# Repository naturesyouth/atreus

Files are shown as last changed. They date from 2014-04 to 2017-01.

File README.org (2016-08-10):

* Atreus Keyboard

The Atreus is a mechanical keyboard designed primarily to match the
shape of human hands and to be as portable as possible. The case
measures 26x12cm and lacks even a number row, relying heavily upon the
=fn= key. There is a circuit board for this design, but it's also
possible to [[http://wiki.geekhack.org/index.php?title=Hard-Wiring_How-To][manually wire the matrix]].

I've seen a number of existing DIY 40% keyboard designs, but most of
them stagger the rows, which I find very annoying now that I've gotten
used to the columnar layout of the [[https://geekhack.org/index.php?topic=22780.0][Ergodox]]. In addition, many of the
designs I've seen waste a lot of room on the space bar, failing to
take into account the fact that the thumb is the strongest and most
versatile of the fingers. This design avoids both these problems while
taking a more couch-friendly single-piece approach.



See [[./changelog.md][the changelog]] for the various revisions made to the design since
its initial release.

** Kits

You can buy [[http://atreus.technomancy.us][Atreus kits]] that have all the parts you need along with
detailed assembly instructions from http://atreus.technomancy.us. If
you'd rather round up all the parts yourself, that's possible too
since the design is completely open source; see the bill of materials
below.

** Layout

Only a handful of punctuation marks (and no digits) are available
unshifted, and all the modifiers are on the bottom row:

 :    q     w     e     r     t       ||       y     u     i     o    p
 :    a     s     d     f     g       ||       h     j     k     l    ;
 :    z     x     c     v     b       ||       n     m     ,     .    /
 :   esc   tab  super shift bksp ctrl || alt space  fn     -     '  enter

The numbers and most of the punctuation are on the fn layer with a
numpad-style arrangement under the right hand:

 :    !    @     up     {    }        ||     pgup    7     8     9    *
 :    #  left   down  right  $        ||     pgdn    4     5     6    +
 :    [    ]      (     )    &        ||       `     1     2     3    \
 :   L2  insert super shift bksp ctrl || alt space   fn    .     0    =

The =L2= key switches it to the function layer, and tapping =L0= here
brings it back to the first layer.

 :  insert home    ↑    end  pgup     ||       ↑     F7    F8    F9   F10
 :    del   ←      ↓     →   pgdn     ||       ↓     F4    F5    F6   F11
 :                           reset    ||             F1    F2    F3   F12
 :              super shift bksp ctrl || alt space   L0             

The [[https://atreus.technomancy.us/tmk][firmware]] includes a number of other options, including
colemak, dvorak, and "software dvorak" which sends keycodes assuming
the OS will perform the translation into dvorak. Adding new layouts or
changing existing ones is easy.

** Parts

*** Switches

This layout has five modifiers and 37 non-modifiers.

I strongly prefer the feel and sound of tactile [[https://deskthority.net/wiki/Matias_switch#Click][Matias Clicky]]
switches for typing. However, I like having [[https://deskthority.net/wiki/Matias_switch#Linear][Matias Linear
switches]] switches on the modifier keys (ctrl, alt, super, shift, and
fn) because the tactile effect has no benefit for keys that are held
down, and giving a different response helps you learn the layout more
quickly.

For users that need to operate in sound-sensitive environments like
open offices or libraries,
[[http://deskthority.net/wiki/Matias_switch#Quiet_click][Matias Quiet
Click]] switches are a popular choice since they still offer tactility
without the noise. Other users prefer switches in the
[[http://deskthority.net/wiki/Cherry_MX][Cherry MX]] family, which use
different keycaps and switch plates but still work fine.

*** Diodes

In order to avoid ghosting, each switch needs a diode. The [[https://www.radioshack.com/product/index.jsp?productId=2062587][1N4148]] is a
readily-available choice, but nearly any signal diode would work.

*** Microcontroller

The circuit board design uses a [[http://www.pololu.com/product/3101][Pololu A-star micro]]. Hand-wired boards
can also use a [[http://www.pjrc.com/teensy/index.html][Teensy 2]] or [[http://arduino.cc/en/Main/ArduinoBoardMicro][Arduino Pro Micro]].

Be sure to get a microcontroller without headers so it will fit in
between the bottom layer and the plate. USB micro is preferred over
USB mini for this reason as well.

*** Keycaps

Caps for Matias switches are included in the official kits. Sculpted
caps are also available [[http://matias.ca/order/#keycaps][from Matias]] or by harvesting from old Alps
keyboards. It's recommended that you use unlabeled keys, because due
to the different sizes and orientations of certain keys (backspace,
shift, enter, etc) many of the labels will be incorrect if present.

Cherry switches have more options. This
[[http://keyshop.pimpmykeyboard.com/products/full-keysets/dsa-blank-sets-1][DSA-shaped base set]] (spherical indentations on the key, same profile for each
row) from Signature Plastics has 52 1x keys plus a few extras we won't
use. There are two "deep dish" keys in that set which you can place
under your index fingers on the home row to help guide your hands to
the right spot without looking. However, you only get a single 1.5x
keycap, and the middle two thumb keys both use them, so you might want
to pick up an extra.

** Circuit Board

The =atreus.rkt= program calculates switch and diode positions based
on row/column counts, spacing, and rotation factors, and emits a
=atreus.kicad_pcb= file. The board outline and traces are done by hand
and are stored in the =header.rktd= and =traces.rktd= files
respectively. The =atreus.kicad_pcb= file can be imported into [[http://kicad-pcb.org][Kicad]]
which can export Gerber files suitable for fabrication. A copy of the
Kicad PCB file is included in the repository if you don't want to
recompile it using Racket. Recompiling is only required if you want to
make changes to the procedurally-generated portions of the board.

Unfortunately most PCB fabricators require a minimum order of 10 or
so, making this impractical for one-offs. The PCB is not required, so
for one-off boards it's usually more sensible to stick with a [[http://atreus.technomancy.us/assembly-hand-wired.pdf][hand-wired build]] instead.

** Case

Layered laser-cut wood or acrylic. The [[http://geekhack.org/index.php?topic%3D54759.msg1304117#msg1304117][mark II case]] (EPS files in the
=case/= directory) features 8 screw holes and a kind of "stair step"
design around the top and bottom of the key clusters; mark I is
pictured below.

The =3mm-alps-all.eps= file contains the top plate, bottom plate, and
switch plate for Matias switches. =3mm.eps= contains the files for
Cherry boards. These pieces can all be cut on 3mm acrylic or wood. The
=spacer.eps= file should be cut on something thicker; between 4.5mm
and 6mm is recommended. The spacer needs to be at least as thick as
the connector of the USB cable you're using.

There is also a programmatically-implemented version of the case
written in OpenSCAD; it is more flexible (you can tweak the number of
rows/cols, etc and recompile) but it doesn't match the canonical case
exactly; in particular the screw holes are placed differently.

The original case (=case-mk-i.svg=) design is also included; it is
slightly less wide and has a minor asymmetry with the screws on the
bottom side.

On a 100W Epilog laser, the 3mm layers cut in about a minute and a
half. I did a run with 6mm acrylic of the other layers which took
nearly 6 minutes.

Wood cases should be finished with sandpaper and finishing oil/wax or
with [[https://atreus.technomancy.us/lacquer.pdf][lacquer]] which
takes longer but feels nicer.

** Firmware

The [[https://atreus.technomancy.us/tmk][TMK firmware]] is
recommended. You should be able to change into the =keyboard/atreus=
directory and run =make KEYMAP=qwerty= (or whichever variant you want)
to produce a qwerty =atreus.hex= file. You will probably want to
create your own layout once you've gotten a chance to try it and see
what works for you. See the readme for instructions of how to upload
it to the keyboard's controller.

There is also the older [[https://github.com/technomancy/atreus-firmware][atreus-firmware]] custom codebase which works
but has fewer features. It is recommended mostly for learning purposes
since the code is much simpler and easier to understand than TMK.

** Bill of Materials

If you don't want to get [[https://atreus.technomancy.us][the kit]] you can source parts yourself. (You
can also order a partial kit if you want to customize some of the
parts.) Using Cherry switches is cheapest unless you can find cheap
Alps-mount keycaps:

- 50 Matias or Cherry switches from mechanicalkeyboards.com
- 50 diodes from radio shack, ebay, or whatever
- 40 1x, 2 1.5x Keycaps from signatureplastics.com OR full keycap set from matias.com
- A-star micro from pololu.com
- Case materials from various sources
- Case laser cutting: 7.5 minutes on a 100W Epilog laser; varies by source
- USB micro cable, get anywhere

Recommended but optional:

- 5 linear Matias or Cherry switches

The base keycap set from Signature Plastics only has one 1.5x key,
which is used for the inner thumb keys. You can use a 1x key for one
of them, but it looks kind of tacky, so I recommend getting a second
1.5x keycap separately.

*** Other Tools

You'll need a soldering iron, solder, and a wire cutter. A multimeter
can come in handy for testing the connections but is optional. You'll
also need eight M3 machine screws with nuts; the length of the screws
depends on the thickness of the acrylic you use. You can add rubber
feet to the bottom to prevent the board from sliding around when
placed on a desk. You'll also need sandpaper and lacquer for the
wooden case.

If you are building a hand-wired board you will also need a glue gun,
hookup wire, and wire strippers.

** Assembly

See the [[https://atreus.technomancy.us/assembly.pdf][assembly instructions]] PDF.

Hand-wired boards will want the [[https://atreus.technomancy.us/assembly-hand-wired.pdf][previous edition of the assembly instructions]].

The LaTeX source to the assembly instructions is in the =assembly= directory.

** Inspiration

These fine projects all provided inspiration for various aspects of
the Atreus, as well as the folks on the =#geekhack= freenode channel.

- [[https://geekhack.org/index.php?topic=22780.0][Ergodox]]
- [[http://deskthority.net/workshop-f7/onehand-20-keyboard-t6617.html][OneHand]]
- [[http://blog.fsck.com/2013/12/better-and-better-keyboards.html][keyboard.io]]
- [[http://geekhack.org/index.php?topic=48718][ErgoT]]

** Builds

If you've built an Atreus, please add your name to [[https://github.com/technomancy/atreus/wiki/BuildLogs][the build logs wiki]].

There's also a [[https://atreus.technomancy.us/list][mailing list]] for people who have built or ordered an
Atreus or are interested in doing so.

** Orestes

A new [[https://www.flickr.com/photos/technomancy/14654421878][experimental build]] uses the [[http://pjrc.com/store/teensy31.html][Teensy 3]] microcontroller and
ARM [[https://github.com/technomancy/orestes/tree/teensy3][Forth-based]] firmware, but this is not yet suitable for general-purpose use.

** License

Copyright © 2014-2016 Phil Hagelberg and contributors

Released under the [[https://www.gnu.org/licenses/gpl.html][GNU GPL version 3]]

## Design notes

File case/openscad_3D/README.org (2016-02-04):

* OpenSCAD Atreus case design

This directory contains a copy =atreus_3D.scad= of the original OpenSCAD script =atreus_case.scad= that
generates Atreus case designs using a number of parameters and is rendered for 3D printing.

The main parameters are:

- =angle= : one half of the angle between the left and the right
  groups of keys
- =n_rows=, =n_cols= : number of rows and columns to use
- =staggering_offsets= : column staggering offsets
- =cable_hole_width= : width of the hole for the USB cable
- =hand_separation= : distance between the left and the right groups
  of keys
- =screw_hole_radius= : radius of screw holes
- =use_notched_holes= (boolean) : whether notched Cherry MX switch
  holes are desired

See comments in =atreus_case.scad= for details.

To use, open this script in OpenSCAD, select *Compile and Render
(CGAL)* in the *Design* menu, then select *Export as DXF...*.

Use OpenSCAD to export .stl as necessary.

Please note that the OpenSCAD version of the case is not a direct port
of the canonical DXF; the screw placement is a little bit different,
and the curve of the bottom edge sticks out a bit more.

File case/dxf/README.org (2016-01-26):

* Case design files

This directory contains design files for a laser cut Atreus case.

- =case_quartered.dxf= has spacers split into 4 parts to make it
  easier to fit everything into a 24 by 12 inch sheet.
- =case.dxf= contains the same design but uses a spacer made out one piece.
- =ready-for-ponoko.svg= is the file successfully used to make an
  Atreus case using Ponoko.
- =keys.dxf= contains Cherry MX switch holes with 1x1 and 1x1.5 key
  outlines. They can be used as building blocks for new case designs.

These files are missing the logo.

Unless you're getting this cut somewhere with size restrictions, you
should probably use the =.eps= files in the parent directory. These
also only work with Cherry MX switches, not Matias or Alps.

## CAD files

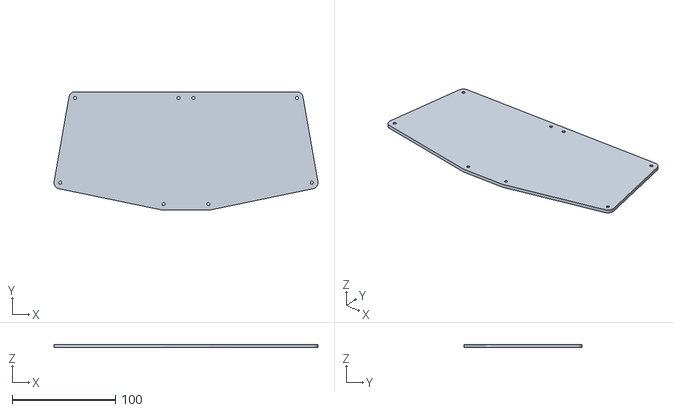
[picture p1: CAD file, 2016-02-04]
case/atreus_bottom.stl
255.3 x 114.5 x 3.00

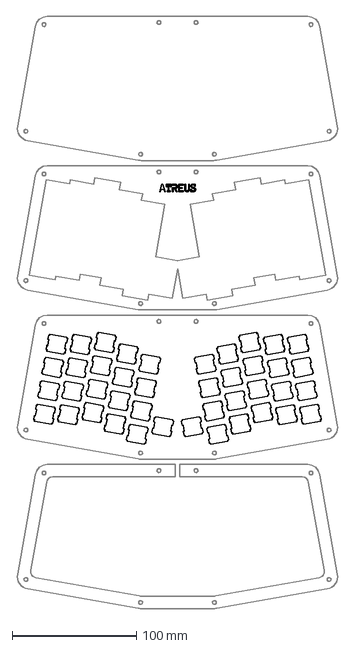
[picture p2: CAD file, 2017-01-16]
case/dxf/#case.dxf
258.8 x 475.8 mm

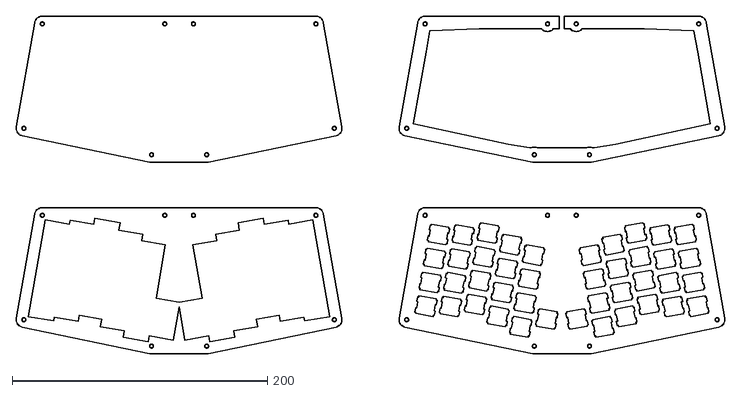
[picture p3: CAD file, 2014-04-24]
case/openscad/atreus_case.dxf
555.3 x 264.5

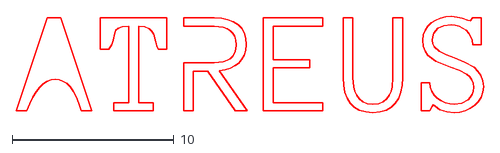
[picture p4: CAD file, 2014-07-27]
logo.dxf
28.9 x 5.95

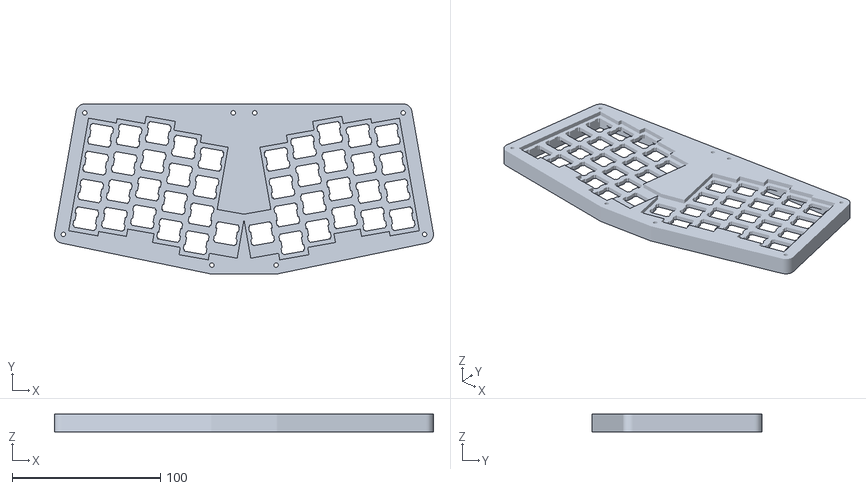
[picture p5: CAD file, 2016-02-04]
case/atreus.stl
255.3 x 114.5 x 12.0

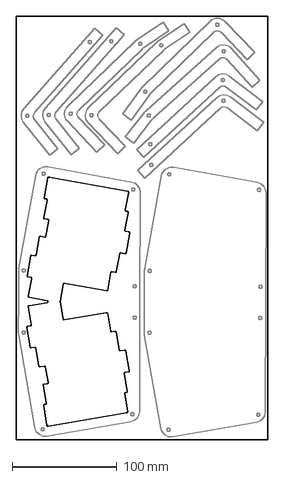
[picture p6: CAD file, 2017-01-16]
case/dxf/case-quartered-collapsed-double-hieght.dxf
239.6 x 404.2 mm

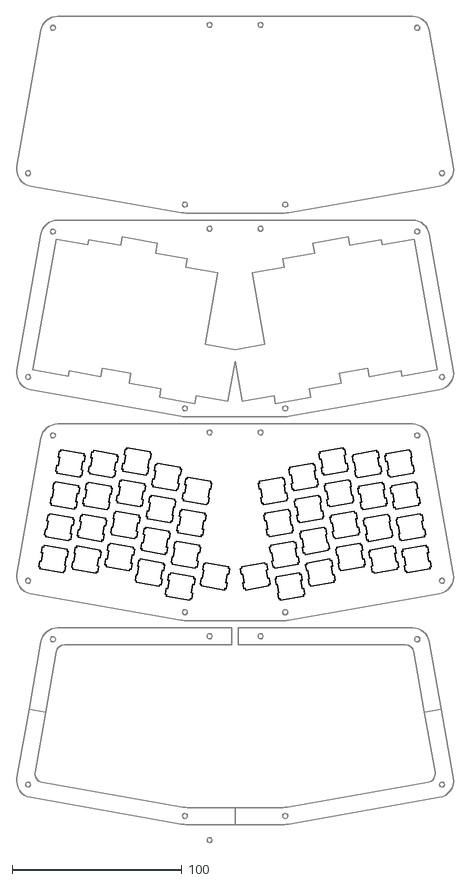
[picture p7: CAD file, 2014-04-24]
case/dxf/case-quartered.dxf
258.3 x 486.5

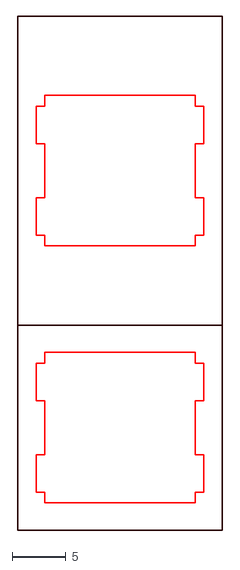
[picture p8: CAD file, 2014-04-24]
case/dxf/keys.dxf
19.1 x 47.8

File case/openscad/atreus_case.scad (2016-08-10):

// -*- mode: c -*-
/* All distances are in mm. */

/* set output quality */
$fn = 50;

/* Distance between key centers. */
column_spacing   = 19;
row_spacing      = column_spacing;

/* This number should exceed row_spacing and column_spacing. The
 default gives a 1mm = (20mm - 19mm) gap between keycaps and cuts in
 the top plate.*/
key_hole_size = 20;

/* rotation angle; the angle between the halves is twice this
   number */
angle = 10;

/* The radius of screw holes. Holes will be slightly bigger due
   to the cut width. */
screw_hole_radius = 1.5;
/* Each screw hole is a hole in a "washer". How big these "washers"
   should be depends on the material used: this parameter and the
   `switch_hole_size` determine the spacer wall thickness. */
washer_radius     = 4 * screw_hole_radius;

/* This constant allows tweaking the location of the screw holes near
   the USB cable. Only useful with small `angle` values. Try the value
   of 10 with angle=0. */
back_screw_hole_offset = 0;

/* Distance between halves. */
hand_separation        = 0;

/* The approximate size of switch holes. Used to determine how
   thick walls can be, i.e. how much room around each switch hole to
   leave. See spacer(). */
switch_hole_size = 14;

/* Sets whether the case should use notched holes. As far as I can
   tell these notches are not all that useful... */
use_notched_holes = true;

/* Number of rows and columns in the matrix. You need to update
   staggering_offsets if you change n_cols. */
n_rows = 4;
n_cols = 5;

/* Number of thumb keys (per hand), try 1 or 2. */
n_thumb_keys = 1;

/* The width of the USB cable hole in the spacer. */
cable_hole_width = 12;

/* Vertical column staggering offsets. The first element should
   be zero. */
staggering_offsets = [0, 5, 11, 6, 3];

/* Whether or not to split the spacer into quarters. */
quarter_spacer = false;

/* Where the top/bottom split of a quartered spacer will be. */
spacer_quartering_offset = 60;

module rz(angle, center=undef) {
  /* Rotate children `angle` degrees around `center`. */
  translate(center) {
    rotate(angle) {
      translate(-center) {
        for (i=[0:$children-1])
          child(i);
      }
    }
  }
}

/* Compute coordinates of a point obtained by rotating p angle degrees
   around center. Used to compute locations of screw holes near the
   USB cable hole. */
function rz_fun(p, angle, center) = [cos(angle) * (p[0] - center[0]) - sin(angle) * (p[1] - center[1]) + center[0],
                                     sin(angle) * (p[0] - center[0]) + cos(angle) * (p[1] - center[1])+ center[1]];

module switch_hole(position, notches=use_notched_holes) {
  /* Cherry MX switch hole with the center at `position`. Sizes come
     from the ErgoDox design. */
  hole_size    = 13.97;
  notch_width  = 3.5001;
  notch_offset = 4.2545;
  notch_depth  = 0.8128;
  translate(position) {
    union() {
      square([hole_size, hole_size], center=true);
      if (notches == true) {
        translate([0, notch_offset]) {
          square([hole_size+2*notch_depth, notch_width], center=true);
        }
        translate([0, -notch_offset]) {
          square([hole_size+2*notch_depth, notch_width], center=true);
        }
      }
    }
  }
};

module regular_key(position, size) {
  /* Create a hole for a regular key. */
  translate(position) {
    square([size, size], center=true);
  }
}

module thumb_key(position, size) {
  /* Create a hole for a 1x1.5 unit thumb key. */
  translate(position) {
    scale([1, 1.5]) {
      translate(-position) {
        regular_key(position, size);
      }
    }
  }
}

module column (bottom_position, switch_holes, key_size=key_hole_size) {
  /* Create a column of keys. */
  translate(bottom_position) {
    for (i = [0:(n_rows-1)]) {
      if (switch_holes == true) {
        switch_hole([0, i*column_spacing]);
      } else {
        regular_key([0, i*column_spacing], key_size);
      }
    }
  }
}

module rotate_half() {
  /* Rotate the right half of the keys around the top left corner of
     the thumb key. Assumes that the thumb key is a 1x1.5 key and that
     it is shifted 0.5*column_spacing up relative to the nearest column. */
  rotation_y_offset = 1.75 * column_spacing;
  for (i=[0:$children-1]) {
    rz(angle, [hand_separation, rotation_y_offset]) {
      child(i);
    }
  }
}

module add_hand_separation() {
  /* Shift everything right to get desired hand separation. */
  for (i=[0:$children-1]) {
    translate([0.5*hand_separation, /* we get back the full separation
                                       because of mirroring */
               0]) child(i);
  }
}

module right_half (switch_holes=true, key_size=key_hole_size) {
  /* Create switch holes or key holes for the right half of the
     keyboard. Different key_sizes are used in top_plate() and
     spacer(). */
  x_offset = 0.5 * row_spacing;
  y_offset = 0.5 * column_spacing;
  thumb_key_offset = y_offset + 0.5 * column_spacing;
  rotate_half() {
    add_hand_separation() {
      for (j=[0:(n_thumb_keys-1)]) {
        if (switch_holes == true) {
          switch_hole([x_offset + j*row_spacing, thumb_key_offset]);
        } else {
          thumb_key([x_offset + j*row_spacing, thumb_key_offset], key_size);
        }
      }
      for (j=[0:(n_cols-1)]) {
        column([x_offset + (j+n_thumb_keys)*row_spacing, y_offset + staggering_offsets[j]], switch_holes, key_size);
      }
    }
  }
}

module screw_hole(radius, offset_radius, position, direction) {
  /* Create a screw hole of radius `radius` at a location
     `offset_radius` from `position`, (diagonally), in the direction
     `direction`. Oh, what a mess this is. */
  /* direction is the 2-element vector specifying to which side of
     position to move to, [-1, -1] for bottom left, etc. */

  /* radius_offset is the offset in the x (or y) direction so that
     we're offset_radius from position */
  radius_offset = offset_radius / sqrt(2);
  /* key_hole_offset if the difference between key spacing and key
     hole edge */
  key_hole_offset = 0.5*(row_spacing - key_hole_size);
  x = position[0] + (radius_offset - key_hole_offset) * direction[0];
  y = position[1] + (radius_offset - key_hole_offset) * direction[1];
  translate([x,y]) {
    circle(radius);
  }
}

module right_screw_holes(hole_radius) {
  /* coordinates of the back right screw hole before rotation... */
  back_right = [(n_cols+n_thumb_keys)*row_spacing,
               staggering_offsets[n_cols-1] + n_rows * column_spacing];
  /* and after */
  tmp = rz_fun(back_right, angle, [0, 2.25*column_spacing]);

  nudge = 0.75;

  rotate_half() {
    add_hand_separation() {
      screw_hole(hole_radius, washer_radius,
                 [row_spacing, 0],
                 [-nudge, -nudge]);
      screw_hole(hole_radius, washer_radius,
                 [(n_cols+n_thumb_keys)*row_spacing, staggering_offsets[n_cols-1]],
                 [nudge, -nudge]);
      screw_hole(hole_radius, washer_radius,
                 back_right,
                 [nudge, nudge]);
    }
  }

  /* add the screw hole near the cable hole */
  translate([washer_radius - tmp[0] - 0.5*hand_separation,
             back_screw_hole_offset]) {
    rotate_half() {
      add_hand_separation() {
        screw_hole(hole_radius,
                   washer_radius,
                   back_right,
                   [nudge, nudge]);
      }
    }
  }
}

module screw_holes(hole_radius) {
  /* Create all the screw holes. */
  right_screw_holes(hole_radius);
  mirror ([1,0,0]) { right_screw_holes(hole_radius); }
}

module left_half(switch_holes=true, key_size=key_hole_size) {
  mirror ([1,0,0]) { right_half(switch_holes, key_size); }
}

module bottom_plate() {
  /* bottom layer of the case */
  difference() {
    hull() { screw_holes(washer_radius); }
    screw_holes(screw_hole_radius);
  }
}

module top_plate() {
  /* top layer of the case */
  difference() {
    bottom_plate();
    right_half(false);
    left_half(false);
  }
}

module switch_plate() {
  /* the switch plate */
  difference() {
    bottom_plate();
    right_half();
    left_half();
  }
}

module spacer() {
  /* Create a spacer. */
  difference() {
    union() {
      difference() {
        bottom_plate();
        hull() {
          right_half(switch_holes=false, key_size=switch_hole_size + 3);
          left_half(switch_holes=false, key_size=switch_hole_size + 3);
        }
    /* add the USB cable hole: */
    translate([-0.5*cable_hole_width, 2*column_spacing]) {
      square([cable_hole_width, (2*n_rows) * column_spacing]);
    }
      }
      screw_holes(washer_radius);
    }
    screw_holes(screw_hole_radius);
  }
}

module spacer_quadrant(spacer_quadrant_number) {
  /* Cut a quarter of a spacer. */
  translate([0, spacer_quartering_offset]) {
    intersection() {
      translate([0, -spacer_quartering_offset]) { spacer(); }
      rotate([0, 0, spacer_quadrant_number * 90]) { square([1000, 1000]); }
    }
  }
}
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

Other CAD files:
case/dxf/switchplate-250w.dxf
case/openscad_3D/atreus_3D.scad
case/dxf/case.dxf

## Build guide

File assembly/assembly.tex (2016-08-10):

\documentclass{article}
\title{Atreus Keyboard Assembly}
\date{ }
\usepackage{graphicx}
\usepackage{geometry}
\usepackage{wrapfig}
\newgeometry{margin=3cm}
\begin{document}
\setlength{\parindent}{0cm}
\maketitle
\section{Prerequisites}

In order to assemble your keyboard, you'll need your kit plus a few
other tools. The kit should contain these parts and a few spares:

\begin{itemize}
\item Case (top plate, switch plate, spacer, bottom plate)
\item Sandpaper
\item Finishing wax (mixture of beeswax and mineral oil)
\item Diodes (42)
\item Key switches (37 tactile or clicky, 5 red)
\item A-Star Micro controller
\item Printed circuit board (PCB)
\item Machine screws and nuts (8 each, 16mm M3 size)
\item Key caps (40 normal, 2 long)
\item USB micro cable
\item Rubber feet
\end{itemize}

You'll also need to have these on hand:

\begin{itemize}
\item Brush for applying finishing wax (a toothbrush will do)
\item Soldering iron and solder (thin solder and an iron with a sharp tip)
\item Wire cutters
\item Rags or paper towels to lay the parts down on during construction
\end{itemize}

\vspace{1em}

The latest version of this document can always be found
online.\footnote{http://atreus.technomancy.us/assembly.pdf} If you're
reading a black-and-white printed copy, you may find some of the
photos clearer in color onscreen. This copy describes the
circuit-board-based kit. If you are hand-wiring a board, see the older
assembly
guide.\footnote{http://atreus.technomancy.us/assembly-hand-wired.pdf}
The photos in this guide depict Matias switches, (with rectangular
switch stems) but you can use Cherry MX switches (with stems shaped
like a +) as well. The assembly steps are the same in either case.

\section{Sanding}

Start by sanding down both sides of each piece. You may want to
hold two pieces together while sanding for strength or placing it on a
flat surface you don't mind scruffing up; too much pressure on a
single plate could damage it.

\vspace{1em}
\noindent\makebox[\textwidth]{%
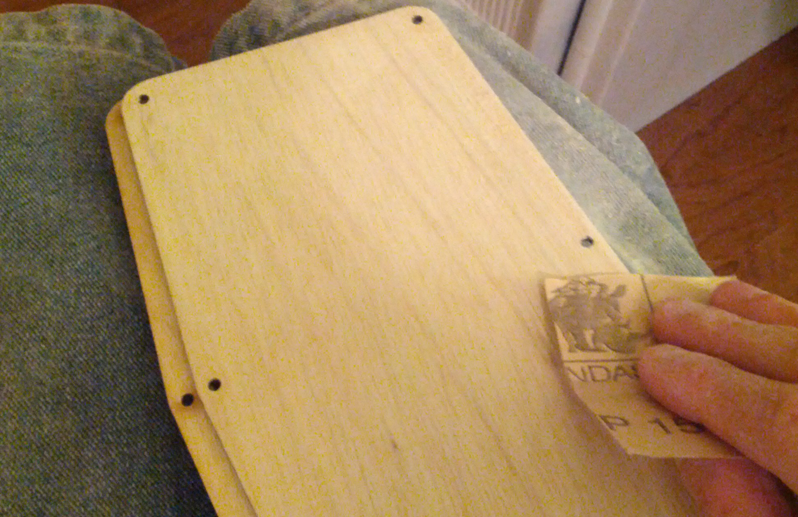
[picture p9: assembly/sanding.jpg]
}
\vspace{1em}

Keep in mind that the top side of the top plate and the bottom side of
the bottom plate are the only surfaces that are exposed to the touch
once the keyboard is fully assembled, so these will need the most
attention when sanding. You can sand the other surfaces as well just
to get the scorch marks off, but you don't need to worry about how
smooth the inner surfaces feel to the touch. Be sure to get all the
wood dust off the pieces before you go on. A clean tack cloth or other
fine cloth works well.

\section{Finishing}

You have two options when it comes to finishing. The easiest way is to
proceed with the wax/oil mixture included in the kit, but you can also
finish it with a spray lacquer. This requires buying more supplies and
takes longer, but it results in a sturdier, shinier
finish.\footnote{http://atreus.technomancy.us/lacquer.gif} The steps
for the lacquered finish are described in a separate
document,\footnote{http://atreus.technomancy.us/lacquer.pdf} and the
rest of this section describes the quicker finishing method.

\vspace{1em}

Some people don't like the look of the exposed edges charred from the
laser cutter. You can choose to sand off the charring, or alternately
cover it all with black ink from a sharpie for a more consistent look.

\vspace{1em}

Open up the wax/oil mixture. Apply some to the brush and start
spreading it over one side of each case piece. The color of the wood
will darken as it absorbs the oil. Try to ensure it's spread
evenly. Be more generous with the oil on the outer exposed
surfaces. Once you've spread it with the brush, you can use your
fingers to work the wax into the wood more deeply. If you need to
reapply the finishing in the future, butcher block conditioner is
readily available in stores and will do the job nicely.

\vspace{1em}
\noindent\makebox[\textwidth]{%
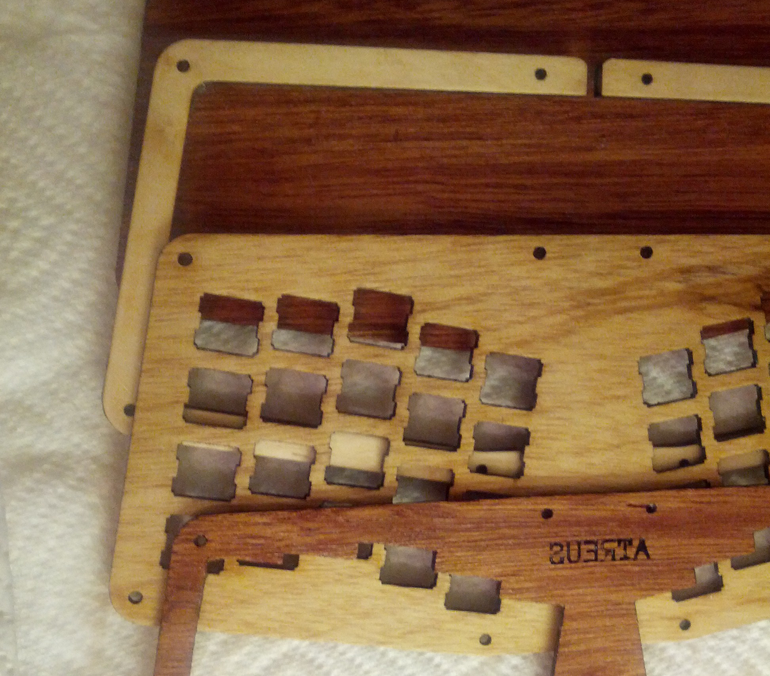
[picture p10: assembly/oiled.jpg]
}
\vspace{1em}

As your brush goes over the edges of the laser-cut wood, it will get
dirty from charred wood particles. After you've finished oiling one
side of each piece, it's best to wash out the brush. Be sure it's
fully dry before going on.

\section{Drying}

Once one side of each piece is finished, you'll need to lay them out
for a half hour or so to let them dry. Once one side is dry, repeat
the process on the other side. After you've finished the construction
you can come back and add another few coats to the outermost surfaces
for a smoother texture. Once it's dried for a while, wipe the excess
off. While you're waiting, you can start soldering the diodes and
controller onto the circuit board, but don't solder any switches in
before the switch plate is ready or you'll just need to remove them
later.

\section{Diodes}

If you've never soldered before, there are plenty of good
introductions online.\footnote{This one from Adafruit is great:
  https://learn.adafruit.com/adafruit-guide-excellent-soldering/tools}
Coat the tip of the hot iron thinly with some solder before you
start. The key is to use the iron to heat both parts of the joint for
a second or two, then bring in a dab of the solder and let it melt and
stick to the component and the circuit board pad.

\vspace{1em}

Take five diodes at a time and bend them into a U shape. Place them
into the diode holes next to each switch slot on the unlabeled side of
the board. Each diode has a black band on it; the band should be
pointing in the direction of the arrow on the printed side of the
board. Once all five are in, pinch the legs of the diodes together to
keep them from falling out, then flip the board over and solder them
in place. Make sure they don't protrude off the board more than necessary.

\vspace{1em}
\noindent\makebox[\textwidth]{%
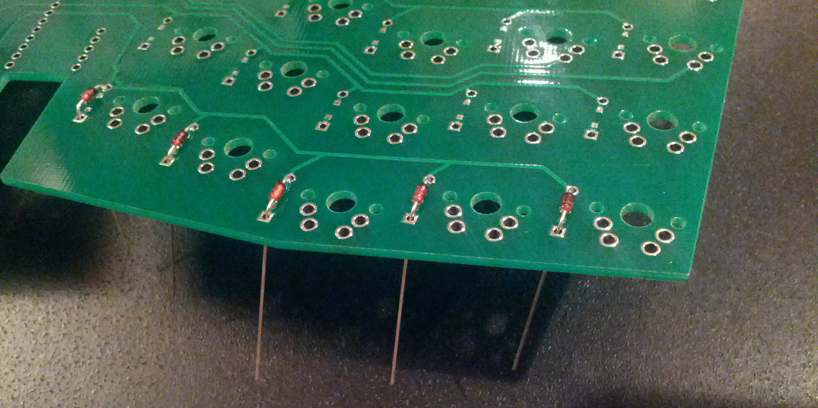
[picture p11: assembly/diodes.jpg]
  }
\vspace{1em}

In the photo the diodes are inserted from the back of the circuit
board, but it will work just as well to insert them from the front as
long as the black band is oriented correctly. Once they're soldered,
trim the diode legs with wire cutters. Grip the diode leg as you
trim it to keep it from flying across the room. Keep the diode legs;
they will be needed in the next step. Repeat until each diode position
is filled.

\section{Controller}

Once the diodes are in place, you can begin attaching the controller.
If the controller came in a pink bag with its own header pins, you may
be tempted to use them to connect the controller to the circuit
board. Don't do this--they are too big and will prevent the case from
closing when you're done. We will be using the diode legs we just
trimmed instead.

\vspace{1em}

First take the PCB with the labeled side down and fill the four corner
holes in the center ``A-STAR'' section with solder. Insert diode legs
into these holes while melting the solder. Then repeat the process for
the other holes on the left, keeping them pointing as straight as possible.

\vspace{1em}
\noindent\makebox[\textwidth]{%
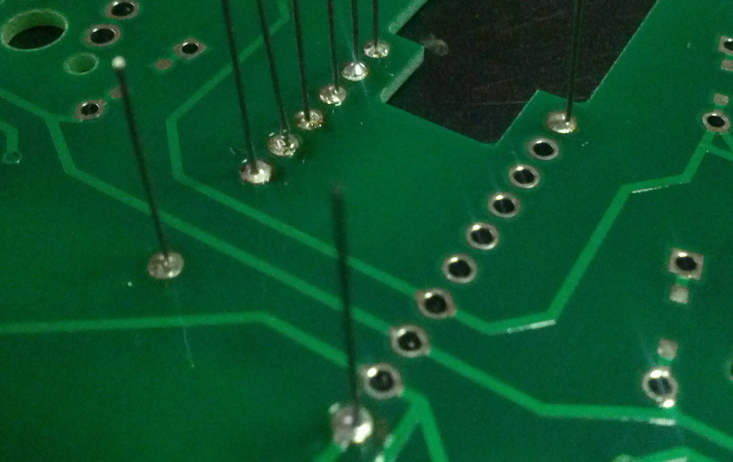
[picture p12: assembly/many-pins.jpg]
  }
\vspace{1em}

Fit the controller over the pins you've attached so far. Solder the
four corner pins already connected to the PCB into the corners of the
controller. (The bottom left corner is unused; the pin above is used
instead.) Try to ensure the controller is as close to the PCB as
possible and not at an angle. Then solder the other left-side diode
legs into the controller as well. Trim them all with your wire
cutters when they are secure.

\vspace{1em}

Eight right-side holes remain. For these, bend four diode legs at a
time into an L shape, and insert them into four of the remaining
holes. Flip the board over and solder the protruding diode legs to the
PCB, then trim them down and flip the board back over. Straighten the
diode legs, then solder and trim them. Repeat for the remaining
unpopulated holes. From the PCB side, all the holes will be used, but
from the controller side, there will be some unused.

\vspace{1em}
\noindent\makebox[\textwidth]{%
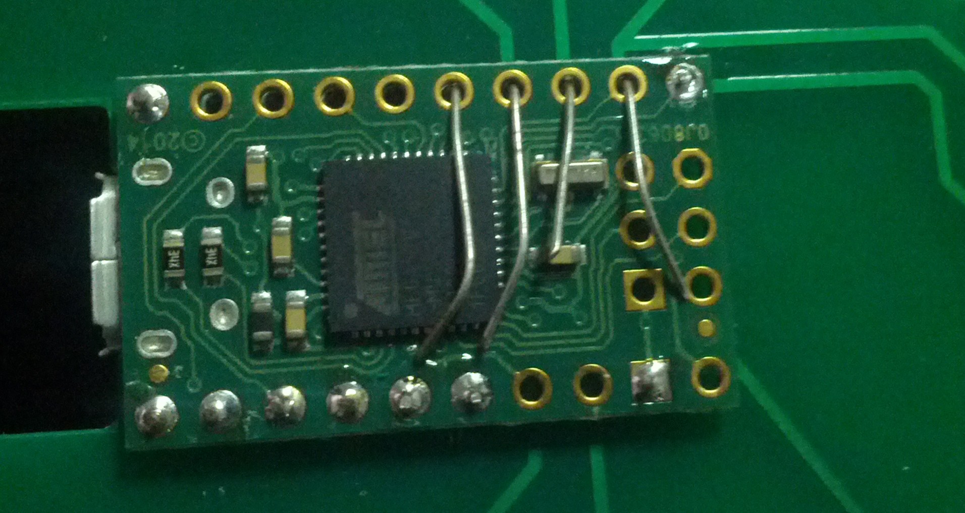
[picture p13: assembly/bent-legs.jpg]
  }
\vspace{1em}

Before you go on, take the time to double-check the solder joints on
the controller. The solder should fill the hole completely without
spilling over to adjacent holes, and the legs should be secure. Also
check that all the diodes are facing the correct direction with the
black band pointing to the bottom of the board.

\section{Firmware}

Installing the firmware now isn't strictly necessary, but it will
allow you to spot mistakes before the board is finished.

\vspace{1em}

\begin{wrapfigure}{r}{0.25\linewidth}
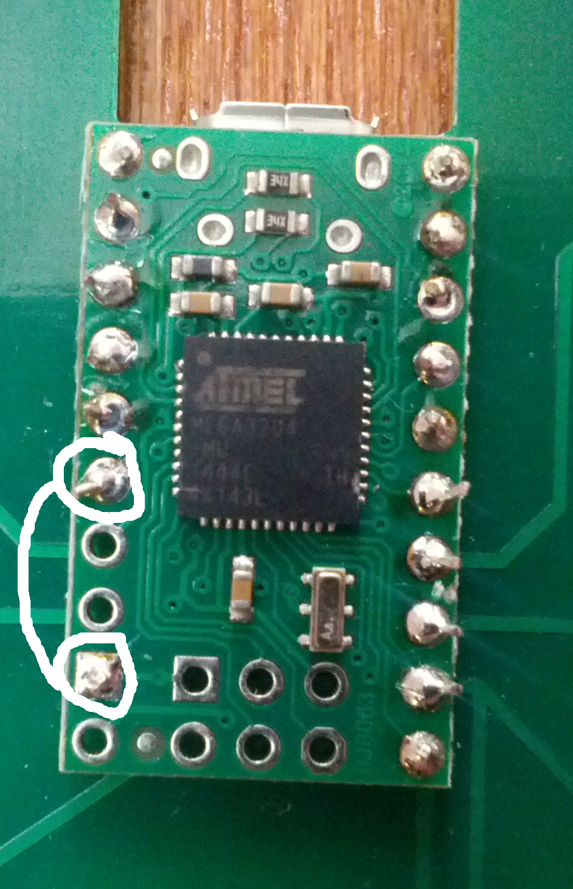
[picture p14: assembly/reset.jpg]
  
\end{wrapfigure}

Plug in the USB micro cable into the controller, and plug the other
side into your computer. Get a copy of the
firmware \footnote{Available at https://atreus.technomancy.us/tmk} and
its dependencies, \texttt{avrdude} and \texttt{gcc-avr}, linked in the
firmware readme. The first time you upload the firmware, you will have
to use the hardware reset to enter the bootloader: take a diode leg or
wire and touch one end to the reset pin and one end to the ground
pin. (These are circled in the photo.)  Touch them together twice in
under a second and the LED underneath will begin pulsing in a
different pattern from the original blinking. This indicates it has
entered the bootloader for 8 seconds.

\vspace{1em}

While in the bootloader, type \texttt{make upload KEYMAP=qwerty
  USB=[...]}  from the firmware directory\footnote{See the firmware
  readme for instructions about determining the USB argument and
  customizing the layout.}. The firmware should be uploaded, and it
will start functioning as a keyboard once switches are connected. Next
time you upload, you can use the reset key instead of touching the
pins together.

\vspace{1em}

If you only want to use the default layout and don't want to bother
with installing everything, the firmware readme also describes simpler
steps for installing a pre-compiled firmware.

\section{Switches}

Next take four switches and place each switch in a corner of the
switch plate. (The case layer with all the holes in it.) The switches
should be oriented so that the side with pins is to the ``north'' of
the board so they will fit into the holes in the circuit board. Put
the switch plate face-down on the table with the pins sticking
up.

\vspace{1em}

Carefully fit the circuit board over the protruding pins with the
labeled side down. Solder those corners to hold the circuit board and
the switch plate together. The switches should be flush with the
PCB. Take care that the switch pins are straight when you insert them;
pushing in a switch with a pin that's a bit bent will bend it flat and
prevent it from poking through the circuit board.

\vspace{1em}
\noindent\makebox[\textwidth]{%
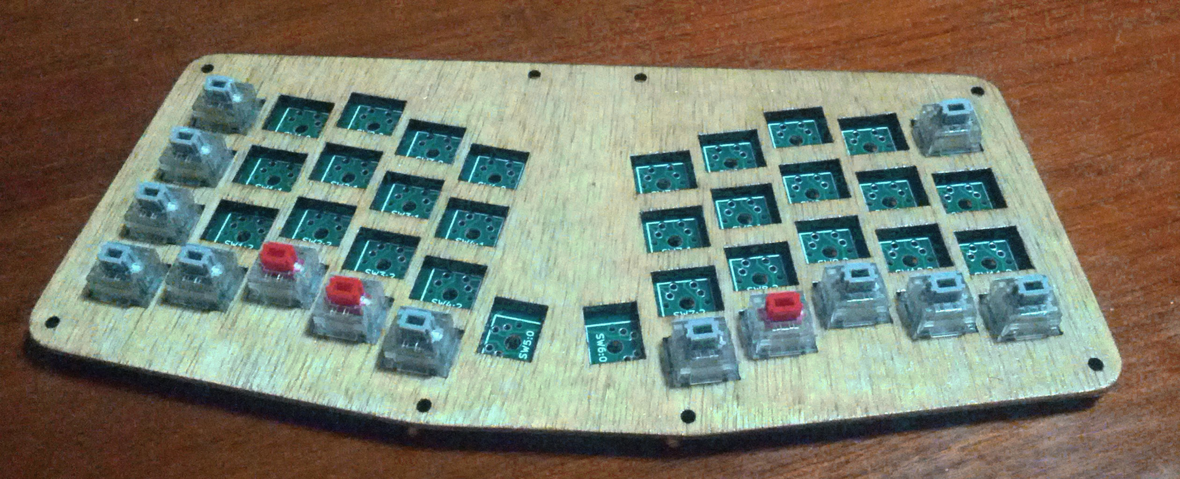
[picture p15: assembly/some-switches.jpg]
  }
\vspace{1em}

Next fill in the rest of the bottom row (SW1:3 through SW10:3) and the
leftmost column (SW0:1 and SW0:2). If your kit has red linear switches
which do not have any tactile bump, you can choose to use these for
the modifier keys (shift, ctrl, alt, etc) or to leave the modifiers as
normal tactile or clicky keys. Since modifier keys are held down, they
do not benefit from tactility like normal keys do, so some people find
they prefer linear keys there, but this is a matter of personal
taste. The modifiers on the bottom row are SW2:3, SW3:3, and SW8:3.
Place normal switches (usually grey or white) here if you want the
modifiers to feel like the other keys, and red ones if not.

\vspace{1em}

Solder the left and right pins of each of the switches you've placed so
far, and then plug it in to test them to ensure that each row and column is
connected back up to the controller correctly. Once you've confirmed
this, solder the rest of the switches, but leave the middle two
sideways ones for last.

\vspace{1em}
\noindent\makebox[\textwidth]{%
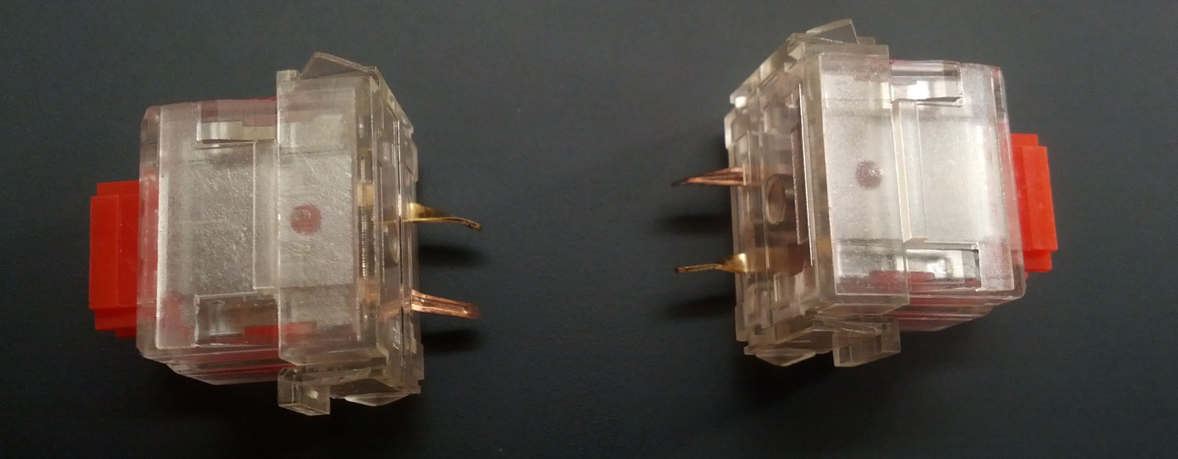
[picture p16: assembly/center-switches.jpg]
  }
\vspace{1em}

\vspace{1em}

%% The main (non-rotated) switches on Matias kits have their pins
%% positioned a bit lower on the switch than Cherry pins; this shifts
%% the whole PCB a bit further down from where it would be on Cherry kits.

%% The holes for the rotated switches are oriented according to their
%% position on Cherry boards because Cherry switches cannot have their
%% pins twisted; they have a plastic post that helps mount it on the
%% PCB, but moving the middle holes down into the Matias-friendly
%% position would make it completely incompatible with Cherry, while
%% leaving it in the Cherry-friendly position simply makes it slightly
%% inconvenient for Matias kits.

Connecting the center two rotated thumb keys (SW5:0 and SW6:0) in kits
with Matias switches requires a little bit of tweaking. (Cherry
switches do not need this step.) The holes for the pins are not
aligned quite under where the pins protrude. A little twisting will
allow them to go in nicely. Note that the two switches must be twisted
in opposite directions since they are oriented facing away from each
other. You can use pliers or even just your wire cutters to twist
them.

\section{Wrapping Up}

If there's a misbehaving switch, it's often caused by a cold
joint. Reflow the solder on both contacts of the switch and the diode
first; if that doesn't fix it, it may be the connection to the
controller. You can follow the traces for the rows back to the middle,
but the columns on the back of the board are obscured when the
keyboard is assembled; you can see them in this PCB
diagram\footnote{https://atreus.technomancy.us/pcb}.
Re-melting the controller's solder joint for the affected row or
column is usually enough to get it working, but in some cases you may
need to reach under to get the joint that connects it to the PCB.

\vspace{1em}

If there is room between the head of the USB cable and the place where
the cable leaves the case, consider adding strain relief by wrapping
the cable with electrical tape or a zip tie at the point just below
where it leaves the case. This will make it so pulling on the cable
does not dislodge it from the controller.

\vspace{1em}

After the switches are all in and tested, place the keycaps. They can
take a fair bit of pressure to go on, so support the underside of the
board while pushing them on. Once the caps are on, they are very
difficult to remove again; don't try to pull them off without
desoldering the switch first.

\vspace{1em}

All that's left is to do is close the case by placing the switch plate
on top of the spacer and bottom plate, placing the top plate on it,
and screwing it together with the nuts facing up. If the controller
was not attached close enough to the circuit board, it may be
necessary to sand down the USB connector in order to close the
case. Before you place the rubber feet on the bottom plate near the
corners, consider giving the outer case another coat or two of wax and
allowing it to dry. If the rubber feet don't stay on with the provided
adhesive, white glue may be needed to secure them.

\vspace{1em}

Congratulations. Enjoy your new keyboard. It will take a
considerable adjustment period to get used to it, but it should result
in much more comfortable and effective typing. Also remember that
you're encouraged to customize the layout to make it truly your
own. Happy typing!

%% \noindent\makebox[\textwidth]{%
%% \includegraphics[width=\linewidth]{finished.jpg}}

\end{document}

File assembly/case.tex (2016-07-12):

\documentclass{article}
\title{Atreus Keyboard Assembly: Lacquered Case}
\date{ }
\usepackage[right=2.5cm, left=2.5cm, top=1cm, bottom=1cm]{geometry}
\usepackage{graphicx}
\usepackage{parskip}
\pagenumbering{gobble}
\begin{document}
\maketitle
\vspace{-3em}

The wooden Atreus Keyboard case can be made with an oil/wax finish,
but if you have the patience to apply several coats of lacquer finish
you can get a very pleasing shiny look with a smoother texture.

\vspace{1em}
\noindent\makebox[\textwidth]{%
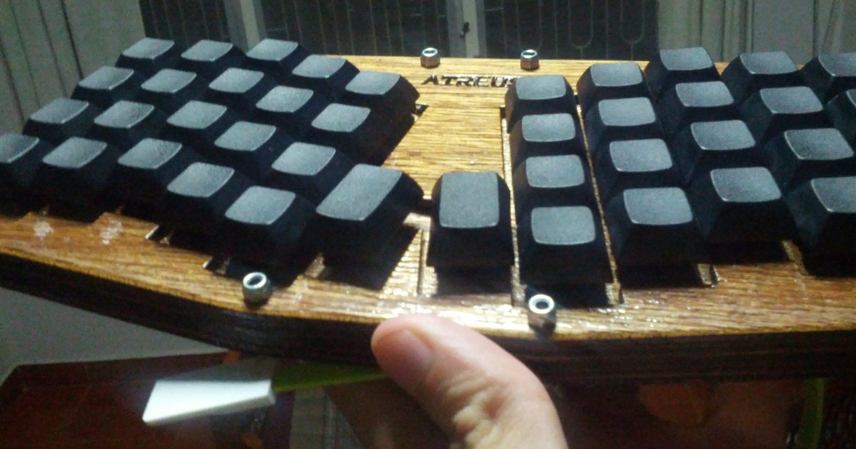
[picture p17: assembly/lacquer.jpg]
}
\vspace{1em}

You'll need a few items in addition to what's in the kit:

\begin{itemize}
\item Fine waterproof sandpaper (between 1000 and 2000 grit)
\item Can of spray lacquer (clear glossy recommended)
\item Newspaper or other material to spray on
\end{itemize}

Start by sanding everything with the 100-grit paper included in the
kit. Pay special attention to remove the scorch marks from the laser
cutting. Some people don't like the look of the exposed edges charred
from the laser cutter. You can choose to sand off the charring to
expose the layered ply or alternately cover it all with black ink from
a sharpie for a more consistent look if you prefer.

Once the case is sanded down all over with coarse sandpaper, find a
good place to spray the lacquer. It should be outdoors, or in a
well-ventilated garage if spraying outdoors is not feasible. Lay down
the newspaper with the pieces of the case on top of it. Spray your
first coat of lacquer to the face-up side of each piece. Try to use a
steady hand and keep the path of the spray overlapping itself just a
small amount as you go to and fro to minimize runs but still cover all
the area. The evenness of the spray matters less on the internal
surfaces of the case, so it's a good time to practice and get the hang
of it.

Check the lacquer directions to see how long your particular product
needs to dry; this can vary from half an hour to nearly a day. Once
your first coat is dry, flip each piece over and spray the other
side. Repeat for a second coat.

After the second coat, you can ignore all surfaces except for the top
of the top plate and the bottom of the bottom plate since only these
are exposed to the outside. At this point you can take in the switch
plate and continue the rest of the keyboard construction while you
wait for remaining coats to dry.

The outer surfaces should have between eight to ten coats applied total. As
you get to the later coats, the end result will be smoother if you can
keep them thinner. After your last coat dries, take your fine
sandpaper and soak it, then sand over the top and bottom surfaces
lightly. If you make any mistakes or are unhappy with the smoothness
of the finish, let it dry and add another layer of lacquer, then try
sanding it again.

As a final step after the case has dried from the wet sanding, take
the wax/oil mixture from the kit and spread some over the outer two
surfaces with your fingers, rubbing it into the finish as a
polish. Let the oil soak into the finish for a few hours. The end
result should look a bit like the wood of a guitar.

Congratulations; you should have a beautifully-finished case. Enjoy!

\end{document}

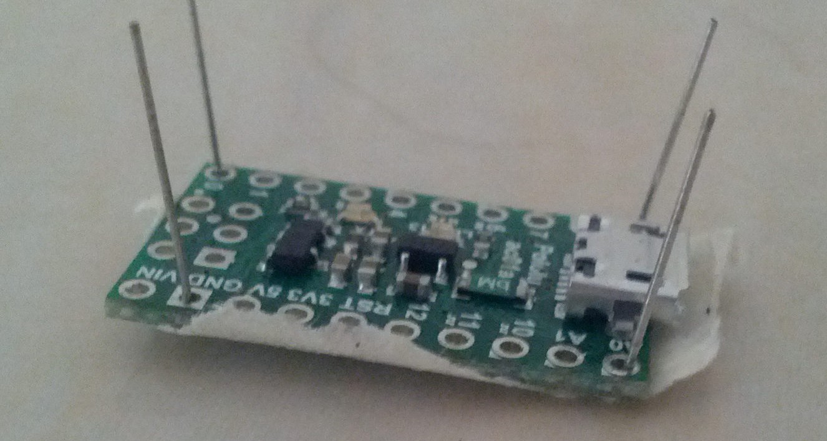
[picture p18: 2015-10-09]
assembly/taped-pins.jpg

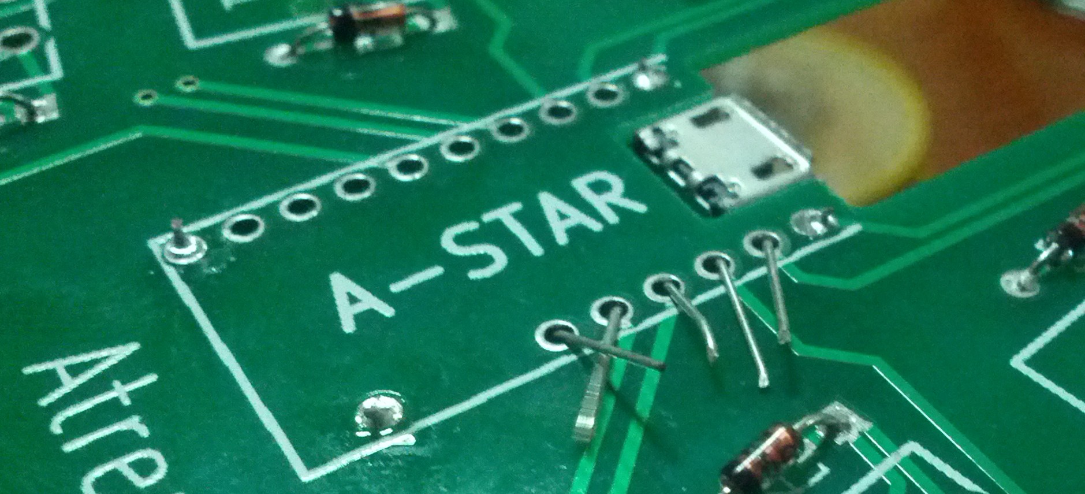
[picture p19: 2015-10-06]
assembly/insert-pin.jpg

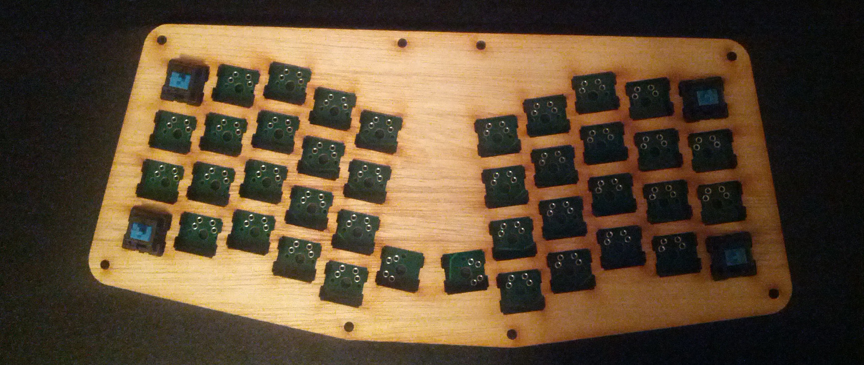
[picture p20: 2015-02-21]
assembly/switch-corners.jpg

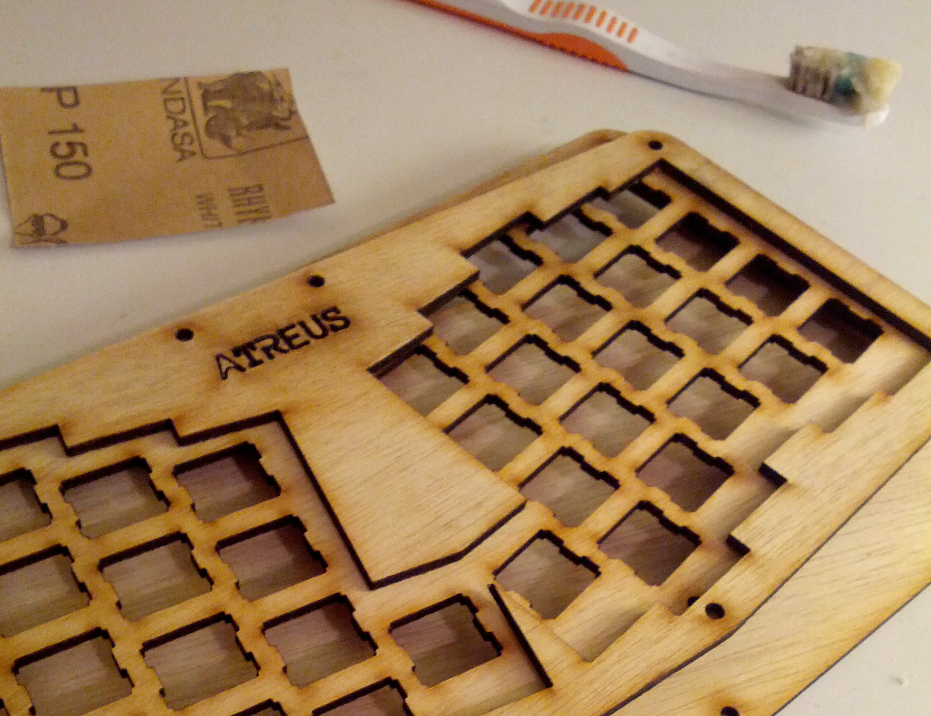
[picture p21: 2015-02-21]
assembly/pre-sanding.jpg

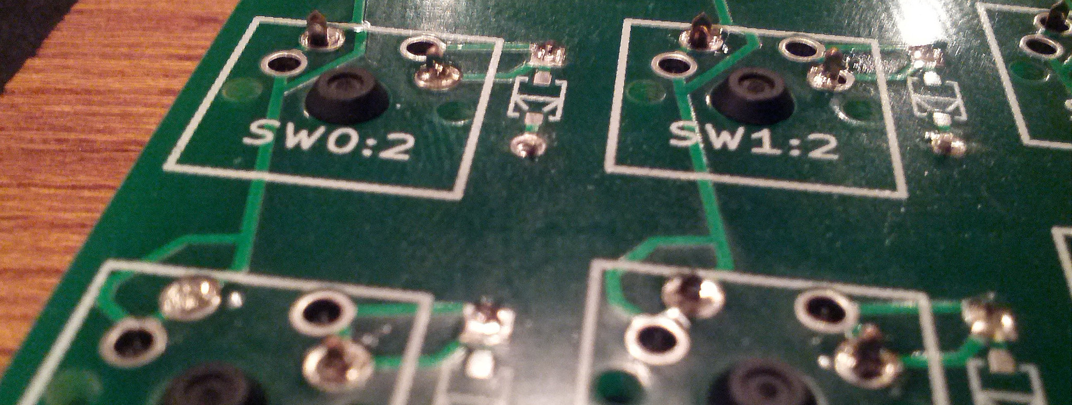
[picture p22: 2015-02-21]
assembly/switches.jpg

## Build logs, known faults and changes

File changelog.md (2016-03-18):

# Change log

## Mark 3.6: 2016-3-14

* TMK is the default firmware.
* New layout with arrows on the fn layer.
* PCB is now label-side up by default.

## Mark 3.5: 2015-6-23

* Change to Matias switches.

## NX-03: 2015-05-08

* Matias Clicky switches.
* Alps-compatible switch plate.

## Mark 3.1: 2014-11-25

* [Second revision of circuit board](http://gerblook.org/pcb/jweM8BcTbgKCL4zsj8tEYj).
* Arrows on L2 shifted over one column.
* Circuit board license changed to match the rest of the Atreus project.

The second revision of the circuit board exposes the reset pin,
removing the need for hookup wire described below. It also removes
[the need to cut a notch in the circuit board](https://www.flickr.com/photos/technomancy/15862732742)
to allow the USB connector more clearance.

The layout changed slightly by shifting the arrow keys on L2 over one
column so they can be hit from the normal position without the pinky key.

## Mark 3: 2014-10-30

* Initial [board design](http://gerblook.org/pcb/zqMY66AEsKz3xehSrdoDV6) in KiCAD + Racket.
* Assembly guide updated to include wood finishing.
* Cable hole in case spacer has rounded edges.
* New layout: multidvorak.
* Switch to Pololu A-Star Micro controller. (also USB mini->micro)

A
[circuit board was designed in KiCAD with the switch placement logic written in Racket](http://technomancy.us/176). The
first revision of the circuit board does not expose the reset pin, so
hookup wire is needed to provide a backup reset mechanism once the board
is fully assembled. The firmware contains a reset mechanism, but if
bugs in the firmware prevent it from being activated, the back case
can be removed and the hookup wires can be connected twice in a second
to initiate a reset.

The new design replaced the Teensy 2 microcontroller with the smaller
[A-Star Micro](http://www.pololu.com/product/3101) which uses a USB
Micro connector instead of USB Mini.

The new multidvorak layout allows the firmware to support hardware
dvorak and software dvorak simultaneously. The edges of the cable hole
are rounded off to reduce strain on the cable.

## NX-02: 2014-08-05

* Matias Quiet Click switches.
* Teensy 3: ARM-based microcontroller.
* Orestes: firmware written in Forth.

An
[experimental prototype](https://www.flickr.com/photos/technomancy/14654421878)
using Matias Quiet Click switches and the ARM-based Teensy 3
controller. The Matias switch shape was supported by cutting the
notches out of each switch hole individually with a knife.

Porting the firmware to the ARM platform was accompanied by porting
[an implementation of Forth](https://github.com/technomancy/orestes/tree/teensy3)
and porting the firmware logic to that.

## Mark 2: 2014-04-22

* New OpenSCAD [case design](https://www.flickr.com/photos/technomancy/14719013574) by Constantine.
* New layouts: hardware dvorak, hardware colemak.
* Assembly guide.

The case was
[redesigned in OpenSCAD](https://github.com/technomancy/atreus/blob/master/case/openscad/atreus_case.scad)
to be easier to produce from mail-order laser cutting services. This
revision can be recognized by its use of eight screws instead of the
original seven. The cuts in the top plate around the switches are also
much closer to the switches themselves.
[A second independent build](http://geekhack.org/index.php?topic=57007.msg1292144)
was documented.

The assembly process is documented properly.

## Mark 1: 2014-04-01

* Custom Atreus firmware in C.
* Layout changes; new layer.

A
[custom Atreus-specific firmware codebase](https://github.com/technomancy/atreus-firmware)
was started. Digits were moved to a numpad arrangement and the L2
layer (function and arrow keys) was added. The first
[third-party build](http://blog.tarn-vedra.de/2014/04/reproducing-keyboard-science_1707.html)
was documented.

## NX-01: 2014-02-22

* [Initial prototype](https://www.flickr.com/photos/technomancy/12805226463)!
* Case hand-drawn in Inkscape.
* Teensy 2 microcontroller, hand-wired matrix.
* Uses TMK firmware.

This was the first Atreus,
[created solely for personal use](http://technomancy.us/173) and
meticulously hand-wired with a number of errors. Support for the
Atreus was
[added to the TMK firmware codebase](https://github.com/technomancy/tmk_keyboard/tree/atreus),
but power-saving bugs in TMK meant that it occasionally dropped key
presses on low-voltage laptops.

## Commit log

2014-05-16 Add the Atreus logo to the .dxf case design file.
    [case.dxf, logo.dxf]
2014-05-16 OpenSCAD design with (optional) 2 thumb keys per hand.
    [atreus_case.scad]
2014-09-10 Round off the cable gap so it's less sharp.
    [atreus_case.scad]
2014-09-12 Update readme to point to assembly.pdf etc.
    Fixes #11.
2014-10-15 Add in-progress PCB design.
    [atreus.brd, atreus.sch]
2014-10-18 Generate PCB from Racket.
2014-10-23 Remove PCB files in favour of atreus.rkt.
    These should be auto-generated by the script rather than kept in the repo.
    [atreus.brd, atreus.sch]
2014-10-23 Fix switch/diode placement in atreus.rkt; add nets
2014-10-25 Fix diode nets; move out edge cuts a bit.
2014-10-25 Add traces.
2014-10-25 Add PCB file generated from atreus.rkt.
    [atreus.kicad_pcb]
2014-10-26 Move diodes to the side of the switch.
    Still missing traces to the microcontroller.
2014-10-28 Retrace with moved diodes; add silkscreening.
    [atreus.kicad_pcb]
2014-10-29 Thicker traces.
2014-10-29 Add diode polarity, remove copper from switch holes.
2014-10-31 Board-mount holes should be non-plated.
2014-11-18 Add notch, expose reset pin in circuit board.
2014-11-26 Finish rev2 of the PCB design.
2015-01-24 Openscad option to split the spacer layer of the case into fourths.
    [atreus_case.scad]
2015-01-24 Clarify non-canonical openscad case.
    Conflicts:
    README.org
2015-01-24 Add description of circuit board to readme.
2015-02-21 Add assembly guide source.
2015-03-02 Check .eps files in for the case.
2015-03-21 Some changes to the assembly guide.
2015-03-21 Advise holding onto the diode leg during trimming.
2015-03-23 Recommend testing before all switches are installed.
2015-05-09 Add Alps switch plate EPS file to case/ dir.
2015-06-08 Add prototype to changelog.
2015-10-06 New instructions for attaching the controller.
2015-10-10 Fix Kicad link. Closes #18.
2016-02-04 adding files for 3D printing
    converted circle( ) to cylinder( ) and square( ) to cube( ) and stacked
    together to make a 2 part case
    [atreus.stl, atreus_3D.scad, atreus_bottom.stl]
2016-02-11 Tidy up last page of assembly instructions.
2016-03-14 New revision of assembly instructions; flipped.
2016-03-18 Add 3mm-alps-all file for convenience.
2016-07-12 Prices on the BOM are way out of date.
    Some of these items don't even exist any more.
2016-08-09 Consider hand separation when placing cable screws
    When increasing the hand_separation screw holes near the USB hole were getting farther apart but the cut for the usb hole is fixed. As the hands separate the screw holes need to be negatively offset.
    [atreus_case.scad]
2017-01-16 added dxf files for aluminium top plate, and restructured quarted case for cutting.
    [#case.dxf, case-quartered-collapsed-double-hieght.dxf, switchplate-250w.dxf]
